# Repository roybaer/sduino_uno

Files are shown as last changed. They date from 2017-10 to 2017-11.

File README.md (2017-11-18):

# sduino UNO

The __sduino UNO__ is an attempt at creating a mechanically and electrically Arduino-UNO-compatible development board based on the __STM8S105K6__ microcontroller.
Both, mechanical and electrical design are to a notable degree based on the [Arduino UNO board](https://store.arduino.cc/arduino-uno-rev3).

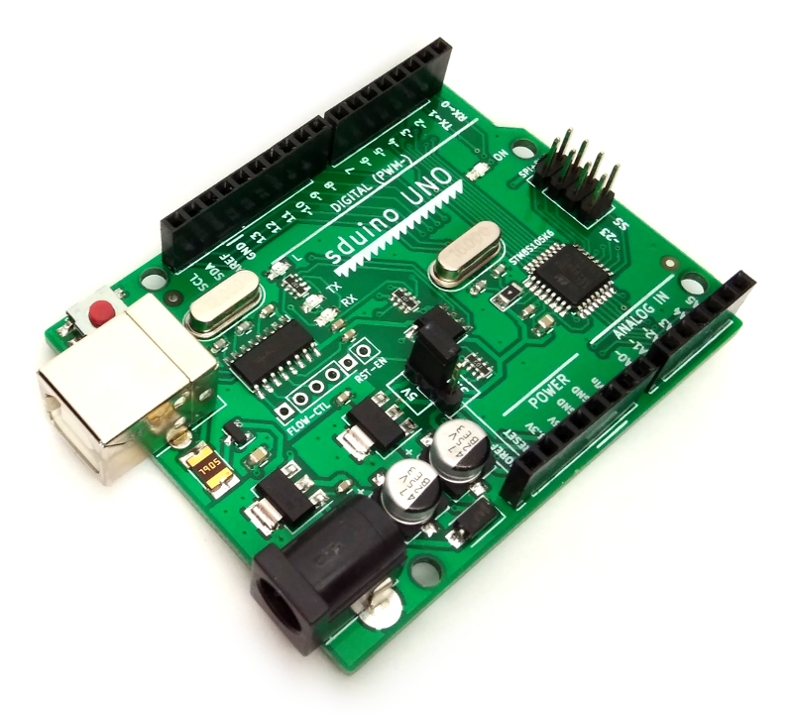
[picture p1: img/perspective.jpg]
sduino UNO board


Components and silkscreen can be viewed in more detail in a [picture of the component side](img/front.jpg) and a [picture of the back side](img/back.jpg) of the assembled board.

## Pin mapping

Number | UNO pin name | ATMEGA328 pin name | STM8S105K6 pin name
-------|--------------|--------------------|----------------------------------------
0      | IO0/RX       | PD0/RXD            | PD6/UART2_RX
1      | IO1/TX       | PD1/TXD            | PD5/UART2_TX
2      | IO2          | PD2/INT0           | PD7/TLI [TIM1_CH4]
3      | IO3          | PD3/INT1/OC2B      | PD2 (HS)/TIM3_CH1 [TIM2_CH3]
4      | IO4          | PD4/T0/XCK         | PD0 (HS)/TIM3_CH2 [TIM1_BKIN]/[CLK_COO]
5      | IO5          | PD5/T1/OC0B        | PD4 (HS)/TIM2_CH1 [BEEP]
6      | IO6          | PD6/AIN0/OC0A      | PD3 (HS)/TIM2_CH2/ADC_ETR
7      | IO7          | PD7/AIN1           | PD1 (HS)/SWIM
8      | IO8          | PB0/ICP1/CLKO      | PC1 (HS)/TIM1_CH1/UART2_CK
9      | IO9          | PB1/OC1A           | PC3 (HS)/TIM1_CH3
10     | IO10/~~SS~~  | PB2/NSS/OC1B       | PC4 (HS)/TIM1_CH4
11     | IO11/MOSI    | PB3/MOSI/OC2A      | PC6 (HS)/SPI_MOSI
12     | IO12/MISO    | PB4/MISO           | PC7 (HS)/SPI_MISO
13     | IO13/SCK     | PB5/SCK            | PC5 (HS)/SPI_SCK
14     | AD0          | PC0/ADC0           | PB0/AIN0 [TIM1_CH1N]
15     | AD1          | PC1/ADC1           | PB1/AIN1 [TIM1_CH2N]
16     | AD2          | PC2/ADC2           | PB2/AIN2 [TIM1_CH3N]
17     | AD3          | PC3/ADC3           | PB3/AIN3 [TIM1_ETR]
18     | AD4/SDA      | PC4/ADC4           | PB5/AIN5 [I2C_SDA]
19     | AD5/SCL      | PC5/ADC5           | PB4/AIN4 [I2C_SCL]
20     | AD6          | --                 | --
21     | AD7          | --                 | --
_22_   | AREF         | AREF               | PF4/AIN12
_23_   | _IO23_       | --                 | PC2 (HS)/TIM1_CH2
_24_   | _IO24/SS_    | --                 | PE5/SPI_NSS
--     | RESET        | NRESET             | NRST
--     | --           | PB6/TOSC1/XTAL1    | PA1/OSCIN
--     | --           | PB7/TOSC2/XTAL2    | PA2/OSCOUT

For evaluation purposes, most of the sduino UNO's functionality can be imitated with an STM8-DISCOVERY board and a USB to Serial converter, as described in [this document](docs/discovery.md).

## Differences

The following paragraphs highlight the most important differences between Arduino UNO and sduino UNO.

### Mechanical

The gap between the upper socket strips has been reduced from 0.06 to 0.05 inches.
This should not significantly impact mechanical compatibility with Arduino UNO shields and increases the available radius around the center of the upper left M3 mounting hole from 2.286 to 2.54 millimeters, which should be just enough to fit in a standard M3 spacer (5mm wrench).

### Electrical

Most importantly, the sduino UNO can be switched between 5V and 3.3V operating voltage.
The RX and TX LEDs are connected to the RX and TX lines (IO pin 0 and 1, respectively) via 1k resistors, rather than to the USB interface chip.

### Functional

Like many Arduino UNO clones, the sduino UNO uses a CH340G USB to serial converter instead of an Atmega16U2 for communication with the host PC.
The USB interface Chip therefore cannot be repurposed as a coprocessor or keyboard/mouse simulator.

There is no analog comparator in the STM8S105K6 microcontroller and AREF is actually an additional analog input.
Its use as reference voltage for A/D conversion has to be imitated in software.
IO11 has no hardware PWM functionality for analog_write, IO8 and IO4 have.
IO2, AD0, AD1 and AD2 can be used as PWM outputs via alternate function mapping.

Likewise, IO10 does not serve as hardware-slave-select line for the SPI bus.
This, however, can mostly be overcome by software-emulation, because the STM8 allows for slave-select to be controlled in software, e.g. in an interrupt handler.
The actual slave-select line has been made available via an exra pin.

### Software

Unfortunately, there is no free C++ compiler available for the STM8 platform, yet.
The Arduino language along with the large pool of existing Arduino sketches can therefore not be used without modifications.

Fortunately, there is the C-based [sduino library](https://github.com/tenbaht/sduino) that in fact inspired the creation of the sduino UNO and that this board borrows its name from.
By using the sduino library, the changes required to run many exsting Arduino sketches on an STM8 platform can be kept within manageable bounds.

Possibilities to bring C++ support to the STM8 platform with a free compiler are being evaluated.

## Copying

Even though the sduino UNO CAD files have been created from scratch and the design is not identical, to avoid legal ambiguity, the CAD files for the sduino UNO board are released under the same creative commons license as those of the Arduino UNO board:

This work is licensed under the Creative Commons Attribution-ShareAlike 2.5 Generic License. To view a copy of this license, visit http://creativecommons.org/licenses/by-sa/2.5/ or send a letter to Creative Commons, PO Box 1866, Mountain View, CA 94042, USA.

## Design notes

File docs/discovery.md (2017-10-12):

Imitating an sduino UNO with an STM8S-DISCOVERY board
=====================================================

The sduino UNO can be imitated using one of ST's STM8S-DISCOVERY boards
combined with a CH340G-based USB to Serial converter with switchable
voltage levels (5V, 3.3V) and jumper wires.
This setup can be completed with an LED connected via LM358 OpAmp and
a voltage regulator for battery operation.
All components can be arranged on or connected to a prototyping shield for
easier use.

The following figures describe the required pin mapping.

STM8S-DISCOVERY
---------------

The STM8S-DISCOVERY board incorporates an STM8S105C6T6 microcontroller with
48 pins that are accessible through four connectors.

      +3V3 VDD U5V

                    0   5   3   4
                   PD6 PD4 PD2 PD0 PE1 PE3
                   PD7 PD5 PD3 PD1 PE0 PE2
                    2   1   6   7
      NRST PA1                                 PG1 PG0
       PA2 VSS                              12 PC7 PC6 11
       VSS VCAP                                VDD VSS
       VDD VDD                              13 PC5 PC4 10
       PA3 PA4                           9¹ EX_PC3 PC2 23
       PA5 PA6                           8¹ EX_PC1 PE5 24
                            A5  A2  A0
                   VSS PB6 PB4 PB2 PB0 PE6
                  VDDA PB7 PB5 PB3 PB1 PE7
                            A4  A3  A1

¹ Requires solder bridges

sduino UNO
----------

The sduino UNO board is designed for an STM8S105K6T6 or -U6 microcontroller
with 32 pins, most of which are accessible through connectors.

     A5  A4  22²     13  12  11  10  9   8   7   6   5   4   3   2   1   0
    PB4 PB5 PF4 VSS PC5 PC7 PC6 PC4 PC3 PC1 PD1 PD3 PD4 PD0 PD2 PD7 PD5 PD6
    
                                                                 12 PC7 U5V
                    U5V                                          13 PC5 PC6 11
                    VDD                                            NRST VSS
                    +3V3                                         23 PC2 PE5 24
    
                    IOREF NRST +3V3 U5V VSS VSS Vin PB0 PB1 PB2 PB3 PB5 PB4
                                                     A0  A1  A2  A3  A4  A5

² Not present on STM8S-DISCOVERY (STM8S105C6T6)

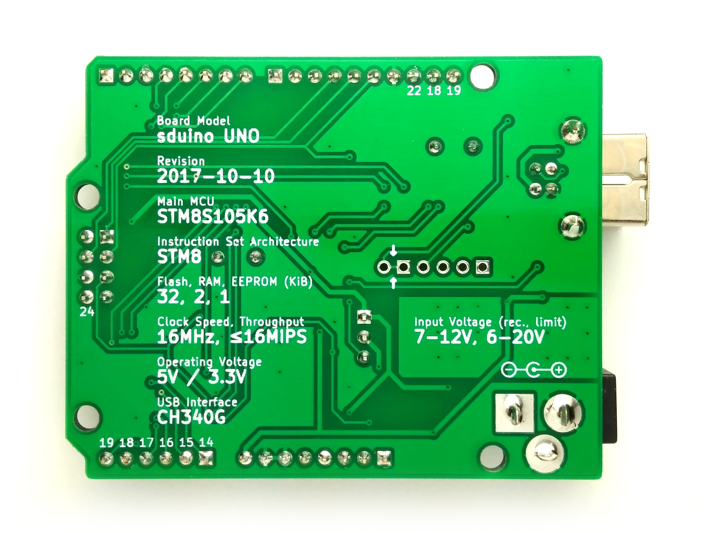
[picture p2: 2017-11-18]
img/back.jpg

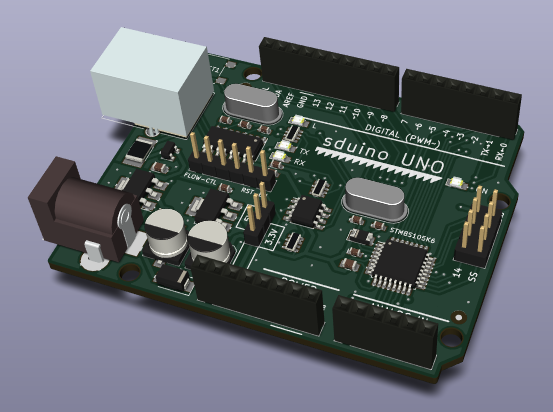
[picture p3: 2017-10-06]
img/rendering_3d.png

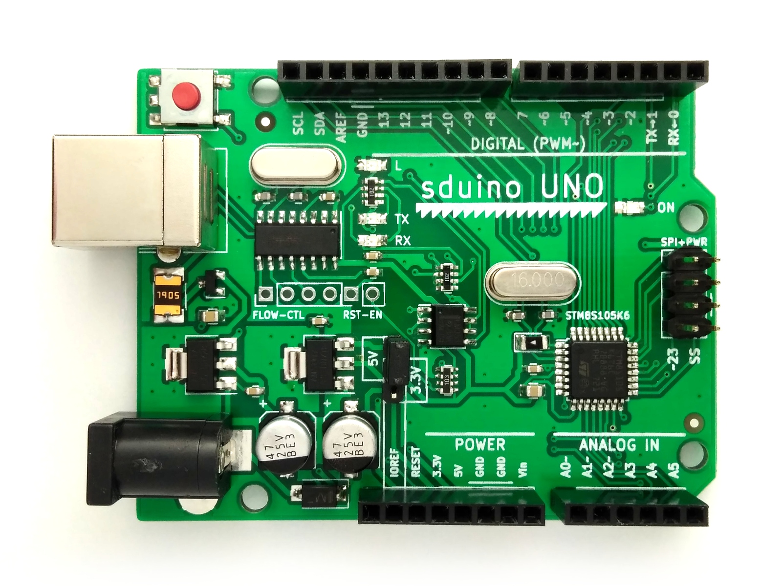
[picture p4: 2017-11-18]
img/front.jpg

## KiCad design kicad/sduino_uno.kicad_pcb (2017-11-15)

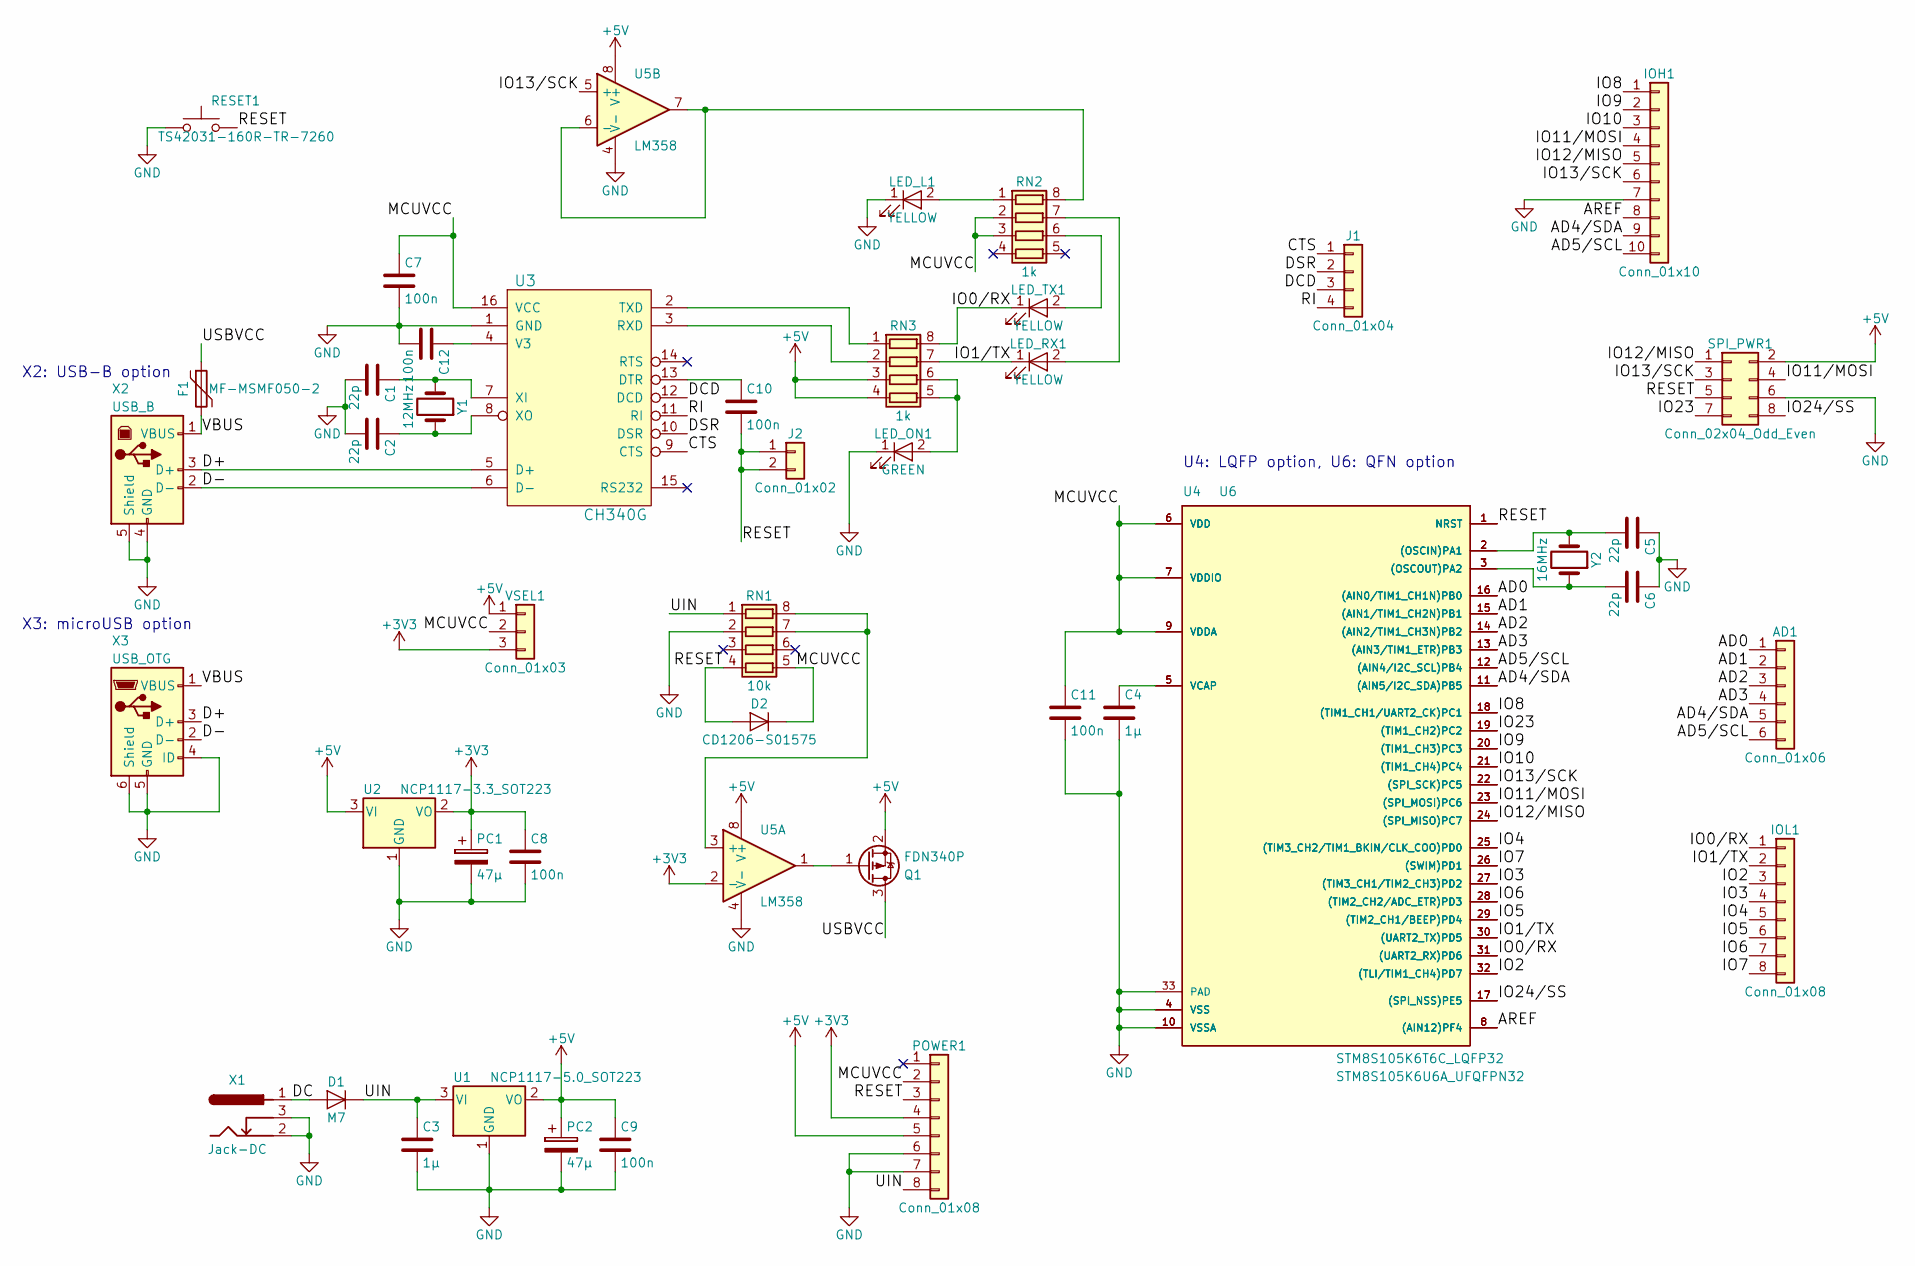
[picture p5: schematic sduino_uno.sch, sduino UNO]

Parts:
AD1: Conn_01x06; Socket_Strip_Straight_1x06_Pitch2.54mm
C1, C2, C5, C6: 22p; C_0603
C3, C4: 1µ; C_0805
C7, C8, C9, C10, C11, C12: 100n; C_0603
D1: M7; D_SMA
D2: CD1206-S01575; D_1206
F1: MF-MSMF050-2; R_1812
IOH1: Conn_01x10; Socket_Strip_Straight_1x10_Pitch2.54mm
IOL1: Conn_01x08; Socket_Strip_Straight_1x08_Pitch2.54mm
J1: Conn_01x04; Pin_Header_Straight_1x04_Pitch2.54mm
J2: Conn_01x02; Pin_Header_Straight_1x02_Pitch2.54mm
LED_L1: YELLOW; LED_0805
LED_ON1: GREEN; LED_0805
LED_RX1: YELLOW; LED_0805
LED_TX1: YELLOW; LED_0805
PC1, PC2: 47µ; CP_Elec_6.3x5.8
POWER1: Conn_01x08; Socket_Strip_Straight_1x08_Pitch2.54mm
Q1: FDN340P; SOT-23
RESET1: TS42031-160R-TR-7260; SW_SPST_B3S-1000
RN1: 10k; R_Array_Concave_4x0603
RN2, RN3: 1k; R_Array_Concave_4x0603
SPI_PWR1: Conn_02x04_Odd_Even; Pin_Header_Straight_2x04_Pitch2.54mm
U1: NCP1117-5.0_SOT223; SOT-223-3Lead_TabPin2
U2: NCP1117-3.3_SOT223; SOT-223-3Lead_TabPin2
U3: CH340G; SOIC-16_3.9x9.9mm_Pitch1.27mm
U4: STM8S105K6T6C_LQFP32; LQFP-32_7x7mm_Pitch0.8mm
U5: LM358; SOIC-8_3.9x4.9mm_Pitch1.27mm
U6: STM8S105K6U6A_UFQFPN32; QFN-32-1EP_5x5mm_Pitch0.5mm
VSEL1: Conn_01x03; Pin_Header_Straight_1x03_Pitch2.54mm
X1: Jack-DC; JACK_ALIM
X2: USB_B
X3: USB_OTG; USB_Micro-B_Molex_47346-0001
Y1: 12MHz; Crystal_HC49-4H_Vertical
Y2: 16MHz; Crystal_HC49-4H_Vertical

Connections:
+3V3: C8.1, PC1.1, POWER1.4, U2.2 (VO), U5.2 (-), VSEL1.3
+5V: C9.1, PC2.1, POWER1.5, Q1.2 (S), RN3.3 (R3.1), RN3.4 (R4.1), SPI_PWR1.2, U1.2 (VO), U2.3 (VI), U5.8 (V+), VSEL1.1
/AD0: AD1.1, U4.16 ((AIN0/TIM1_CH1N)PB0), U6.16 ((AIN0/TIM1_CH1N)PB0)
/AD1: AD1.2, U4.15 ((AIN1/TIM1_CH2N)PB1), U6.15 ((AIN1/TIM1_CH2N)PB1)
/AD2: AD1.3, U4.14 ((AIN2/TIM1_CH3N)PB2), U6.14 ((AIN2/TIM1_CH3N)PB2)
/AD3: AD1.4, U4.13 ((AIN3/TIM1_ETR)PB3), U6.13 ((AIN3/TIM1_ETR)PB3)
/AD4/SDA: AD1.5, IOH1.9, U4.11 ((AIN5/I2C_SDA)PB5), U6.11 ((AIN5/I2C_SDA)PB5)
/AD5/SCL: AD1.6, IOH1.10, U4.12 ((AIN4/I2C_SCL)PB4), U6.12 ((AIN4/I2C_SCL)PB4)
/AREF: IOH1.8, U4.8 ((AIN12)PF4), U6.8 ((AIN12)PF4)
/CTS: J1.1, U3.9 (CTS)
/D+: U3.5 (D+), X2.3 (D+), X3.3 (D+)
/D-: U3.6 (D-), X2.2 (D-), X3.2 (D-)
/DC: D1.2 (A), X1.1
/DCD: J1.3, U3.12 (DCD)
/DSR: J1.2, U3.10 (DSR)
/IO0/RX: IOL1.1, LED_TX1.1 (K), RN3.8 (R1.2), U4.31 ((UART2_RX)PD6), U6.31 ((UART2_RX)PD6)
/IO1/TX: IOL1.2, LED_RX1.1 (K), RN3.7 (R2.2), U4.30 ((UART2_TX)PD5), U6.30 ((UART2_TX)PD5)
/IO2: IOL1.3, U4.32 ((TLI/TIM1_CH4)PD7), U6.32 ((TLI/TIM1_CH4)PD7)
/IO3: IOL1.4, U4.27 ((TIM3_CH1/TIM2_CH3)PD2), U6.27 ((TIM3_CH1/TIM2_CH3)PD2)
/IO4: IOL1.5, U4.25 ((TIM3_CH2/TIM1_BKIN/CLK_COO)PD0), U6.25 ((TIM3_CH2/TIM1_BKIN/CLK_COO)PD0)
/IO5: IOL1.6, U4.29 ((TIM2_CH1/BEEP)PD4), U6.29 ((TIM2_CH1/BEEP)PD4)
/IO6: IOL1.7, U4.28 ((TIM2_CH2/ADC_ETR)PD3), U6.28 ((TIM2_CH2/ADC_ETR)PD3)
/IO7: IOL1.8, U4.26 ((SWIM)PD1), U6.26 ((SWIM)PD1)
/IO8: IOH1.1, U4.18 ((TIM1_CH1/UART2_CK)PC1), U6.18 ((TIM1_CH1/UART2_CK)PC1)
/IO9: IOH1.2, U4.20 ((TIM1_CH3)PC3), U6.20 ((TIM1_CH3)PC3)
/IO10: IOH1.3, U4.21 ((TIM1_CH4)PC4), U6.21 ((TIM1_CH4)PC4)
/IO11/MOSI: IOH1.4, SPI_PWR1.4, U4.23 ((SPI_MOSI)PC6), U6.23 ((SPI_MOSI)PC6)
/IO12/MISO: IOH1.5, SPI_PWR1.1, U4.24 ((SPI_MISO)PC7), U6.24 ((SPI_MISO)PC7)
/IO13/SCK: IOH1.6, SPI_PWR1.3, U4.22 ((SPI_SCK)PC5), U5.5 (+), U6.22 ((SPI_SCK)PC5)
/IO23: SPI_PWR1.7, U4.19 ((TIM1_CH2)PC2), U6.19 ((TIM1_CH2)PC2)
/IO24/SS: SPI_PWR1.8, U4.17 ((SPI_NSS)PE5), U6.17 ((SPI_NSS)PE5)
/MCUVCC: C7.1, C11.1, D2.1 (K), POWER1.2, RN1.5 (R4.2), RN2.2 (R2.1), RN2.3 (R3.1), U3.16 (VCC), U4.6 (VDD), U4.7 (VDDIO), U4.9 (VDDA), U6.6 (VDD), U6.7 (VDDIO), U6.9 (VDDA), VSEL1.2
/RESET: C10.2, D2.2 (A), J2.1, J2.2, POWER1.3, RESET1.2, RN1.4 (R4.1), SPI_PWR1.5, U4.1 (NRST), U6.1 (NRST)
/RI: J1.4, U3.11 (RI)
/UIN: C3.1, D1.1 (K), POWER1.8, RN1.1 (R1.1), U1.3 (VI)
/USBVCC: F1.1, Q1.3 (D)
/VBUS: F1.2, X2.1 (VBUS), X3.1 (VBUS)
GND: C1.2, C2.2, C3.2, C4.2, C5.1, C6.1, C7.2, C8.2, C9.2, C11.2, C12.2, IOH1.7, LED_L1.1 (K), LED_ON1.1 (K), PC1.2, PC2.2, POWER1.6, POWER1.7, RESET1.1, RN1.2 (R2.1), SPI_PWR1.6, U1.1 (GND), U2.1 (GND), U3.1 (GND), U4.4 (VSS), U4.10 (VSSA), U5.4 (V-), U6.4 (VSS), U6.10 (VSSA), U6.33 (PAD), X1.2, X1.3, X2.4 (GND), X2.5 (Shield), X3.4 (ID), X3.5 (GND), X3.6 (Shield)
unnamed: C1.1, U3.7 (XI), Y1.2
unnamed: C2.1, U3.8 (XO), Y1.1
unnamed: C4.1, U4.5 (VCAP), U6.5 (VCAP)
unnamed: C5.2, U4.2 ((OSCIN)PA1), U6.2 ((OSCIN)PA1), Y2.2
unnamed: C6.2, U4.3 ((OSCOUT)PA2), U6.3 ((OSCOUT)PA2), Y2.1
unnamed: C10.1, U3.13 (DTR)
unnamed: C12.1, U3.4 (V3)
unnamed: LED_L1.2 (A), RN2.1 (R1.1)
unnamed: LED_ON1.2 (A), RN3.5 (R4.2), RN3.6 (R3.2)
unnamed: LED_RX1.2 (A), RN2.7 (R2.2)
unnamed: LED_TX1.2 (A), RN2.6 (R3.2)
unnamed: Q1.1 (G), U5.1
unnamed: RN1.7 (R2.2), RN1.8 (R1.2), U5.3 (+)
unnamed: RN2.8 (R1.2), U5.6 (-), U5.7
unnamed: RN3.1 (R1.1), U3.2 (TXD)
unnamed: RN3.2 (R2.1), U3.3 (RXD)

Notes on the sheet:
U4: LQFP option, U6: QFN option
X2: USB-B option
X3: microUSB option

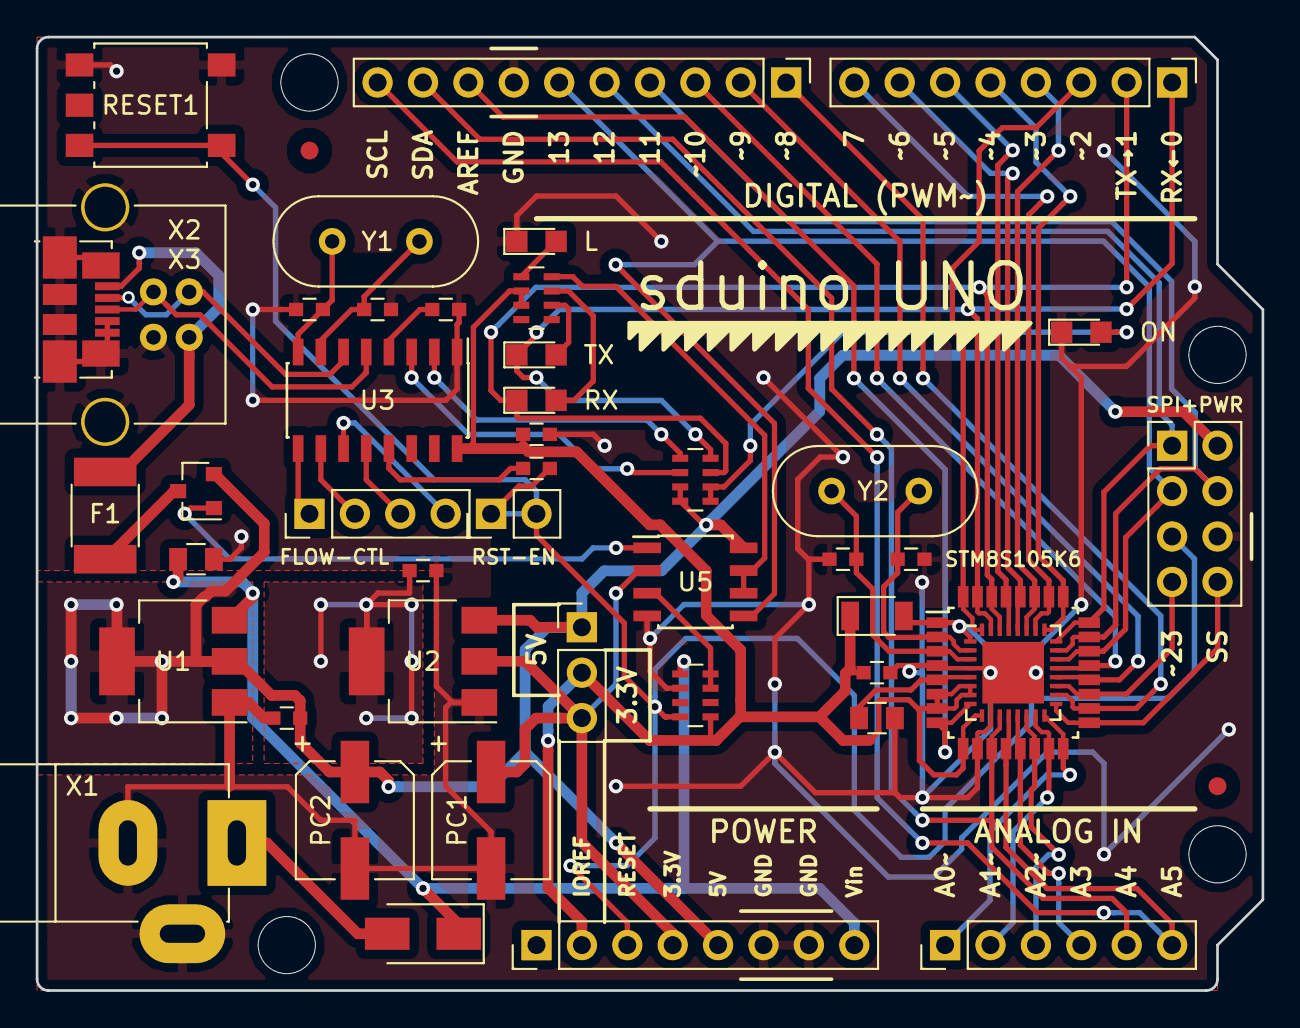
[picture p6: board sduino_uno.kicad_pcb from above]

Board: 2 copper layers, 68.6 x 53.3 mm, 45 parts (0 on the bottom side), 54 nets.

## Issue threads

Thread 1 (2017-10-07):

comments on the schematic and PCB

tenbaht, 2017-10-07:
This looks amazing! I am looking forward to see the first prototypes!

Looking at the schematic I would like to comment on the hardware:
- to initially program a serial bootloader it would be very handy to have a ST-Link compatible 4-pin SWIM connector. I suggest using the same pinout as used for the stm8sblue PCB: RST, GND, SWIM, MCUVCC
- The serial connection between the CH340 and the CPU looks weired to me. Really through the LEDs? Maybe the pins RN2-2 and RN2-3 are supposed to connect to MCUVCC and the IO0/RX and IO1/TX labels should be connected to RN3-7 and RN3-8?
- it might be useful to be able to open the connection between CH340/TXD and STM8/RxD in case the pin is used as an output pin. Solderbridge? Jumper?
- Does J2 really connects to RESET two times? Maybe RESET and GND?
- I am not sure if Q1 is always guaranteed to connect USBVCC to +5V if UIN is not present. U5 is not powered before Q1 is active, but Q1 can't be active before U5A outputs a valid signal. Possible deadlock? Maybe use the unused resistor RN1/3-6 to pull Q1/G to GND?

If you are planning to develop this design further into a commercial product it might be worth to:
- add decoupling filters to VBUS and DC to reduce EM emissions (ferrite beards 220r@100MHz and 1nF+100nF capacitors)
- additional ESD protection on the USB port might be useful

general:

- for people not familiar with kicad it might be convenient to add the schematic as pdf to the repository

PCB:
- a GND guard ring from pin 4 around Y2 and the clock signals would help **a lot** with the EM values.
- the via for SCL under Y2 might connect to the crystal housing after assembly
- SDA is a very sensible signal, but it is routed right under Y2, even on the top side. Might cause malfunctions in I2C communication later.
- rearrage C1, C2 and Y1 is in [Atmel application note AVR186](http://www.atmel.com/Images/Atmel-8128-Best-Practices-for-the-PCB-Layout-of-Oscillators_ApplicationNote_AVR186.pdf)

IMHO it would be worth the effort to move Y2 closer to the CPU and get the I2C signals out of the way. It might help to use a smaller cyrstal. E.g. the [FA-238 series in size 3225](https://www.digikey.com/product-detail/en/epson/FA-238-16.0000MB-C3/SER3686TR-ND/2403378). The price difference to a HC49-type is only a few cents. Resonators with integrated capacitors are another option, e.g. [AVX PRQC series](https://www.digikey.com/product-detail/en/avx-corp-kyocera-corp/PRQC16.00CR5010X000/1253-1675-1-ND/5870331) or [Abracon AWSCR series](https://www.digikey.com/product-detail/en/abracon-llc/AWSCR-16.00CV-T/535-10008-1-ND/2001631)

roybaer, 2017-10-08:
Thanks for the constructive comments!  I appreciate them a lot.

In order:
- The STM8S105 devices, among others, have an integrated ROM bootloader that briefly listens for programming data on all UART and SPI ports, provided that the program flash is empty or the respective option byte is set.  SWIM programming should therefore never be needed, except for mishaps where the bootloader enable option has accidentally been disabled.  In that case the board can still be flashed via jumper wires.  I therefore chose to omit a dedicated SWIM header.
- Damnit!  Thanks a lot!  Of course it is supposed to connect the way you pointed out.
- Neither the Arduinos nor their clones have that, but I'll take it into consideration.
- Yes, J2 just replaces the solder bridge found on the Arduino.  You can cut the reset line on the bottom side where the arrows are and solder on a jumper header.  That way J1 and J2 can be left unpopulated by default.
- That part of the circuit has been taken from the Arduino reference design without modification, so I consider it well tested.

The USB to CH340G wiring is taken from the CH340G application notes and is largely identical to that found on the (admittedly CE-less) Arduino clones.  So for now (10 piece prototype run), I'd consider additional EMC and ESD measures unnecessary gold plating.

Concerning PDFs:  I might upload PDFs once I have working boards.  No need to spam the git history.

PCB:
- There already is a GND ring around Y2, C5, C6, D2, C11 and C4 that connects to pin 4.  It goes through half a dozen VIAs but should be better than nothing.
- The VIA should be below the solder mask.
- The placement of the I2C lines is clearly not optimal, indeed.  It was the best routing I could come up with, though.  Let's hope that possible 16MHz interference does not harm the 100kHz signal too much.  If it does, one might have to switch to the internal 16MHz resonator.
- Maybe I'll flip C2.  There is not much more I can do without starting over.

I did consider using a smaller resonator.  Most of them look next to impossible to hand-solder, though.  That is why I went for the common HC49-THT type.  They are also much cheaper (in volume) and easier to source.

And once again thank you for pointing out that major TX/RX brain fart!  That could have resulted in a great deal of disappointment and frustration.

tenbaht, 2017-10-08:
Ok, that all makes sense. I wasn't aware of the build-in bootloader. Hopefully, we will not miss the SWIM connector more often then expected.

I just added support for this proposed pin mapping in the new [experimental branch of sduino](https://github.com/tenbaht/sduino/tree/experimental), but since I don't have any similar CPU it is completely untested. Feedback would be highly appreciated!

roybaer, 2018-08-04:
I think we can close this.

Closed 2018-08-04.

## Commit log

2017-10-06 board revision 2017-10-01 and documentation
    [sduino_uno.kicad_pcb, sduino_uno.sch]
2017-10-08 revision 2017-10-08 - fix major error in TX/RX wiring (LEDs were connected in series) - improve ground fill surrounding crystals - rename IO14 to IO23 - add some pin numbers on the back side - update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
    [sduino_uno.kicad_pcb, sduino_uno.sch]
2017-10-10 board revision 2017-10-10 (minor PCB changes) - optimized ground fills - reduced thermal relief around the regulators' thermal pads
    [sduino_uno.kicad_pcb]
2017-11-11 photo of board revision 2017-10-10
2017-11-15 board revision 2017-11-15 (minor corrections and clarifications)
    - use more precise names for some components
    - adjust footprint of DC jack to better fit the DC jack
    - adjust thermal relief around pads of 0603 components
    [sduino_uno.kicad_pcb, sduino_uno.sch]

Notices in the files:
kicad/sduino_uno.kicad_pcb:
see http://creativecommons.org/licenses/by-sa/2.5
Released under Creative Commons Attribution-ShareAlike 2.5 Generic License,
